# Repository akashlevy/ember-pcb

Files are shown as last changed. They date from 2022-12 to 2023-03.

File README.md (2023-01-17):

# EMBER PCB

This is the PCB for interfacing the EMBER macro with FPGA, power supplies, probing, and power measurement.

## EMBER Sister Repositories

- Digital: https://github.com/akashlevy/ember-digital
- Analog: https://code.stanford.edu/tsmc40r/emblem-analog (PRIVATE & TECHNOLOGY-SPECIFIC)
- Physical Design: https://code.stanford.edu/tsmc40r/emblem-pd (PRIVATE & TECHNOLOGY-SPECIFIC)
- PCB: https://github.com/akashlevy/ember-pcb
- FPGA (Genesys2) Project: https://github.com/akashlevy/ember-fpga
- PetaLinux Configuration: https://github.com/akashlevy/ember-petalinux-config
- Python SPI Environment: https://github.com/akashlevy/ember-python

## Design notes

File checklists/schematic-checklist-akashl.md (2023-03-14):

# Schematic review checklist

## General

* [ ] CAD ERC 100% clean. If some errors are invalid due to toolchain quirks, each exception must be inspected and signed
off as invalid.
* [ ] Verify pin numbers of all schematic symbols against datasheet or external interface specification document (if not yet board proven).
  * [ ] Confirm FMC pins are done correctly
  * [ ] Confirm EMBER pins are oriented correctly
  * [ ] Confirm EMBER pins are mapped correctly to package
  * [ ] Confirm EMBER pins are mapped correctly to socket
  * [ ] Confirm all 256 EMBER pins are routed
* [ ] Schematic symbol matches chosen component package and footprint
* [ ] Thermal pads are connected to correct power rail (may not always be ground)
  * [ ] LP5912 has thermal pads to ground. Hole size on footprint is increased to 10 mil to accommodate design rules.
* [ ] Debug interfaces are not power gated in sleep mode

## Passive components
* [ ] Power/voltage/tolerance ratings specified as required
  * [ ] Regulators work up to 500 mA (200 mA needed)
  * [ ] Switches are rated for up to 300 mA @ 6V (200 mA @ 3.3V needed)
  * [ ] Capacitors are rated for 630 V (3.3V needed)
  * [ ] Ferrite beads are rated for 5A (200 mA needed)
* [ ] Ceramic capacitors appropriately de-rated for C/V curve
  * [ ] Capacitors only used with DC power supplies
* [ ] Polarized components specified in schematic if using electrolytic caps etc.

## Power supply

### System power input

* [ ] Fusing and/or reverse voltage protection at system power inlet
  * [ ] FPGA should take care of this
* [ ] Check total input capacitance and add inrush limiter if needed
  * [ ] Probably ok for test board...
* [ ] Check SMA/coaxial connections (ground shielding on outside, signal on inside)

### Regulators

* [ ] Under/overvoltage protection configured correctly if used
  * [ ] Implemented in regulators and at FPGA and EMBER macro
* [ ] Verify estimated power usage per rail against regulator rating
  * [ ] Max total current is 200 mA (during RESET), which is within all regulators' ratings (500 mA) and FPGA power rating (3 A)
* [ ] Current-sense resistors on power rails after regulator output caps, not in switching loop
  * [ ] Yes, done on power measurement daughter board...
* [ ] Remote sense used on low voltage or high current rails (N/A)
* [ ] Linear regulators and voltage reference ICs are stable with selected output cap ESR
  * [ ] NEED TO DOUBLE CHECK THAT THIS IS OK... OUTPUT CAP CAN BE HIGH IF ALL CAPS ARE POPULATED
* [ ] Confirm power rail sequencing against device datasheets

### Decoupling
* [ ] Decoupling present for all ICs
* [ ] Decoupling meets/exceeds vendor recommendations if specified
* [ ] Bulk decoupling present at PSU

### General
* [ ] All power inputs fed by correct voltage
* [ ] Check high-power discrete semiconductors and passives to confirm they can handle expected load
* [ ] Analog rails filtered/isolated from digital circuitry as needed
  * [ ] Separate planes should help

## Signals

### Digital

* [ ] Signals are correct logic level for input pin
  * [ ] All signals will be at FPGA setting
* [ ] Pullups on all open-drain outputs (N/A)
* [ ] Pulldowns on all PECL outputs (N/A)
* [ ] Termination on all high-speed signals (N/A)
* [ ] AC coupling caps on gigabit transceivers (N/A)
* [ ] TX/RX paired correctly for UART, SPI, MGT, etc (N/A)
* [ ] Differential pair polarity / pairing correct (N/A)
* [ ] Active high/low enable signal polarity correct (N/A)
* [ ] I/O banking rules met on FPGAs etc
* [ ] When using auto-sensing level shifters, ensure the intended receiver doesn't have a pullup/down (N/A)

### Analog

* [ ] RC time constant for attenuators sane given ADC sampling frequency (N/A)
* [ ] Verify frequency response of RF components across entire operating range. Don't assume a "1-100 MHz" amplifier has the (N/A)
same gain across the whole range.
* [ ] Verify polarity of op-amp feedback (N/A)

### Clocks

* [ ] All oscillators meet required jitter / frequency tolerance. Be extra cautious with MEMS oscillators as these tend to have higher jitter. (N/A)
* [ ] Correct load caps provided for discrete crystals (N/A)
* [ ] Crystals only used if IC has an integrated crystal driver (N/A)
* [ ] Banking / clock capable input rules met for clocks going to FPGAs
    * [ ] Xilinx FPGAs: single ended clocks use _P half of differential pairs
    * [ ] If possible, create dummy design with all clocks and other key signals and verify it P&R's properly

### Strap/init pins
* [ ] Pullup/pulldowns on all signals that need defined state at boot
  * [ ] FPGA takes care of this
* [ ] Strap pins connected to correct rail for desired state
  * [ ] DIP switches are strapped to io_pwr
* [ ] JTAG/ICSP connector provided for all programmable devices (N/A)
* [ ] Config/boot flash provided for all FPGAs or MPUs without internal flash (N/A)
* [ ] Reference resistors correct value and reference rail (N/A)

### External interface protection

* [ ] Power outputs (USB etc) current limited
  * [ ] Regulators do this
* [ ] ESD protection on data lines going off board
  * [ ] Exist in EMBER and FPGA

### Debugging / reworkability

* [ ] Use 0-ohm resistors vs direct hard-wiring for strap pins when possible (N/A)
* [ ] Provide multiple ground clips/points for scope probes
  * [ ] Available on power header and analog header
* [ ] Dedicated ground in close proximity to analog test points
* [ ] Test points on all power rails
  * [ ] Accessible through power headers
* [ ] Test points on interesting signals which may need probing for bringup/debug
  * [ ] Heartbeat
  * [ ] All EMBER signals can be probed on bottom through socket

## Thermal

* [ ] Power estimates for all large / high power ICs
  * [ ] EMBER should never exceed 100 mA
* [ ] Thermal calculations for all large / high power ICs
* [ ] Specify heatsinks as needed
  * [ ] Thermal vias on regulator ICs connect to ground plane

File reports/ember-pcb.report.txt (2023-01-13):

PCB statistics report
=====================
- Date: Friday, January 13, 2023 at 03:17:59 PM
- Project: ember-pcb
- Board name: ember-pcb

Board
-----
- Width: 4695.00 mils
- Height: 3935.00 mils
- Area: 18474825.00 sq. mils

Pads
----
- Through hole: 506
- SMD: 482
- Connector: 0
- NPTH: 8

Vias
----
- Through vias: 378
- Blind/buried: 0
- Micro vias: 0

Components
----------

| | Front Side | Back Side | Total |
|---|---|---|---|
|THT: | 8  | 0  | 8  |
|SMD: | 23  | 1  | 24  |
|Total:  | 31  | 1  | 32  |
| | | | |

Drill holes
-----------

| Count | Shape | X Size | Y Size | Plated | Via/Pad | Start Layer | Stop Layer |
|---|---|---|---|---|---|---|---|
| 441 | Round | 33.86 mils | 33.86 mils | PTH | Pad | F.Cu | B.Cu |
| 349 | Round | 10.00 mils | 10.00 mils | PTH | Via | F.Cu | B.Cu |
| 43 | Round | 39.37 mils | 39.37 mils | PTH | Pad | F.Cu | B.Cu |
| 29 | Round | 15.75 mils | 15.75 mils | PTH | Via | F.Cu | B.Cu |
| 10 | Round | 59.06 mils | 59.06 mils | PTH | Pad | F.Cu | B.Cu |
| 6 | Round | 10.00 mils | 10.00 mils | PTH | Pad | F.Cu | B.Cu |
| 4 | Round | 35.43 mils | 35.43 mils | NPTH | Pad | F.Cu | B.Cu |
| 4 | Round | 31.50 mils | 31.50 mils | PTH | Pad | F.Cu | B.Cu |
| 2 | Round | 98.43 mils | 98.43 mils | NPTH | Pad | F.Cu | B.Cu |
| 2 | Round | 98.43 mils | 98.43 mils | PTH | Pad | F.Cu | B.Cu |
| 2 | Round | 50.00 mils | 50.00 mils | NPTH | Pad | F.Cu | B.Cu |

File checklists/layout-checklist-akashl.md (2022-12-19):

# Layout review checklist

## General

* [ ] [Schematic review](schematic-checklist.md) complete and signed off, including pin swaps done during layout
* [ ] Layout DRC 100% clean

## Decoupling

* [ ] Decoupling caps as close to power pins as possible
  * [ ] Huge planes, can solder on decoupling caps onto power pins on socket after the fact as well
* [ ] Low inductance mounting used for decoupling (prefer ViP if available, otherwise "[]8" shaped side vias (N/A)

## DFM / yield enhancement

* [ ] All design rules within manufacturer's capability (N/A)
* [ ] Minimize use of vias/traces that push fab limits
* [ ] Controlled impedance specified in fab notes if applicable (N/A)
* [ ] Confirm impedance calculations include soldermask, or mask removed from RF traces (N/A)
* [ ] Stackup verified with manufacturer and specified in fab notes
* [ ] Board finish specified in fab notes
* [ ] If panelizing, add panel location indicators for identifying location-specific reflow issues (N/A)
* [ ] (recommended) Layer number markers specified to ensure correct assembly
* [ ] Fiducials present (on both sides of board) if targeting automated assembly
* [ ] Fiducial pattern asymmetric to detect rotated or flipped boards
* [ ] Soldermask/copper clearance on fiducials respected
* [ ] Panelization specified if required (N/A)

## Footprints

* [ ] Confirm components are available in the selected package
* [ ] Confirm components (especially connectors and power regulators) are capable of desired current in the selected package
* [ ] Verify schematic symbol matches the selected package
* [ ] Confirm pinout diagram is from top vs bottom of package
* [ ] (recommended) PCB printed 1:1 on paper and checked against physical parts
* [ ] 3D models obtained (if available) and checked against footprints
* [ ] Soldermask apertures on all SMT lands and PTH pads

## Differential pairs
* [ ] Routed differentially
* [ ] Skew matched
* [ ] Correct clearance to non-coupled nets

## High-speed signals

* [ ] Sufficient clearance to potential aggressors
* [ ] Length matched if required
  * [ ] See reports/ember-pcb.nets.xlsx for statistics on signal net length from FPGA
* [ ] Minimize crossing reference plane splits/slots or changing layers, use caps/stitching vias if unavoidable
* [ ] Confirm fab can do copper to edge of PCB for edge launch connectors
* [ ] Double-check pad width on connectors and add plane cutouts if needed to minimize impedance discontinuities (N/A)

## Power
* [ ] Minimal slots in planes from via antipads
* [ ] Sufficient width for planes/traces for required current

## Sensitive analog
* [ ] Guard ring / EMI cages provided if needed (N/A)
* [ ] Physically separated from high current SMPS or other noise sources (N/A)
* [ ] Consider microphone effect on MLCCs if near strong sound sources (N/A)

## Mechanical
* [ ] Confirm all connectors to other systems comply with the appropriate mechanical standard (connector orientation, key position, etc)
  * [ ] Confirm FMC orientation is correct (see Xilinx FMC female adapter photo in docs vs. 3D view of board)
  * [ ] Confirm PGA orientation is correct
* [ ] LEDs, buttons, and other UI elements on outward-facing side of board
* [ ] Keep-outs around PCB perimeter, card guides, panelization mouse-bites, etc respected
* [ ] Stress-sensitive components (MLCC) sufficiently clear from V-score or mouse bite locations, and oriented to reduce (N/A)
bending stress
* [ ] Clearance around large ICs for heatsinks/fans if required (N/A)
* [ ] Clearance around pluggable connectors for mating cable/connector
* [ ] Clearance around mounting holes for screws
* [ ] Plane keepouts and clearance provided for shielded connectors, magnetics, etc (N/A)
* [ ] Confirm PCB dimensions and mounting hole size/placement against enclosure or card rack design
* [ ] Verify mounting hole connection/isolation
  * [ ] Grounded
* [ ] Components not physically overlapping/colliding
* [ ] Clearance provided around solder-in test points for probe tips

## Thermal

* [ ] Thermal reliefs used for plane connections (unless via is used for heatsinking)
* [ ] Solid connections used to planes if heatsinking
  * [ ] Used for regulators
* [ ] Ensure thermal balance on SMT chip components to minimize risk of tombstoning

## Solder paste

* [z] No uncapped vias in pads (except low-power QFNs where some voiding is acceptable)
* [ ] QFN paste prints segmented (N/A)
* [ ] Small pads 100% size, larger pads reduced to avoid excessive solder volume
* [ ] No paste apertures on card edge connectors or test points

## Solder mask

* [ ] Confirm SMD vs NSMD pad geometry
* [ ] Adequate clearance around pads (typ. 50 um)

## Silkscreen

* [ ] Text size within fab limits
* [ ] Text not overlapping drills or component pads
* [ ] Text removed entirely in, or moved outside of, high component/via density areas
* [ ] Traceability markings (rev, date, name, etc) provided
* [ ] Silkscreen box provided for writing/sticking serial number (N/A)
* [ ] Text mirrored properly on bottom layer
* [ ] Test points labeled if space permits

## Flex specific
* [ ] Components oriented to reduce bending forces (N/A)
* [ ] Teardrops on all wire-to-pad connections (N/A)

## CAM production
* [ ] KiCAD specific: rerun DRC and zone fills before exporting CAM files to ensure proper results
* [ ] Export gerber/drill files at the same time to ensure consistency
* [ ] Visually verify final CAM files to ensure no obvious misalignments

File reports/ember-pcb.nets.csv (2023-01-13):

Net Code | Net Name | Pad Count | Via Count | Via Length | Track Length | Die Length | Net Length
070 | /rram_busy | 2 | 0 | 0.00 mils | 3937.01 mils | 0.00 mils | 3937.01 mils
089 | /sclk | 2 | 0 | 0.00 mils | 3937.02 mils | 0.00 mils | 3937.02 mils
090 | /sc | 2 | 0 | 0.00 mils | 3937.28 mils | 0.00 mils | 3937.28 mils
091 | /mosi | 2 | 2 | 104.49 mils | 3832.61 mils | 0.00 mils | 3937.10 mils
092 | /read_dac_config_1 | 2 | 1 | 9.12 mils | 3919.43 mils | 0.00 mils | 3928.55 mils
093 | /rst_n | 2 | 0 | 0.00 mils | 3937.02 mils | 0.00 mils | 3937.02 mils
094 | /read_dac_config_0 | 2 | 1 | 52.25 mils | 3833.52 mils | 0.00 mils | 3885.76 mils
095 | /byp | 3 | 1 | 61.37 mils | 3539.87 mils | 0.00 mils | 3601.24 mils
096 | /man | 3 | 1 | 61.37 mils | 3217.64 mils | 0.00 mils | 3279.01 mils
097 | /di_42 | 2 | 1 | 52.25 mils | 3833.21 mils | 0.00 mils | 3885.46 mils
098 | /clamp_ref_1 | 2 | 1 | 52.25 mils | 3832.71 mils | 0.00 mils | 3884.96 mils
099 | /clamp_ref_2 | 2 | 1 | 52.25 mils | 3832.61 mils | 0.00 mils | 3884.86 mils
100 | /clamp_ref_3 | 2 | 1 | 9.12 mils | 3927.91 mils | 0.00 mils | 3937.03 mils
101 | /clamp_ref_4 | 2 | 1 | 9.12 mils | 3918.77 mils | 0.00 mils | 3927.90 mils
102 | /wl_dac_config_0 | 2 | 1 | 52.25 mils | 3832.92 mils | 0.00 mils | 3885.17 mils
103 | /core_pwr | 9 | 4 | 245.48 mils | 2419.02 mils | 0.00 mils | 2664.50 mils
104 | /vdd_fsm | 9 | 0 | 0.00 mils | 0.00 mils | 0.00 mils | 0.00 mils
105 | /vdd | 11 | 0 | 0.00 mils | 0.00 mils | 0.00 mils | 0.00 mils
106 | /vdd_dac | 7 | 0 | 0.00 mils | 0.00 mils | 0.00 mils | 0.00 mils
107 | /vsa | 6 | 0 | 0.00 mils | 0.00 mils | 0.00 mils | 0.00 mils
110 | /io_pwr | 8 | 4 | 245.48 mils | 2755.67 mils | 0.00 mils | 3001.15 mils
111 | /vddio_fsm | 17 | 0 | 0.00 mils | 0.00 mils | 0.00 mils | 0.00 mils
112 | /vddio | 13 | 0 | 0.00 mils | 0.00 mils | 0.00 mils | 0.00 mils
113 | /vddio_dac | 13 | 0 | 0.00 mils | 0.00 mils | 0.00 mils | 0.00 mils
116 | /wl_source_pin | 2 | 0 | 0.00 mils | 2380.95 mils | 0.00 mils | 2380.95 mils
117 | /bl_source_pin | 3 | 0 | 0.00 mils | 5710.48 mils | 0.00 mils | 5710.48 mils
118 | /sl_source_pin | 3 | 0 | 0.00 mils | 4810.73 mils | 0.00 mils | 4810.73 mils
119 | /iref_test | 2 | 0 | 0.00 mils | 5828.94 mils | 0.00 mils | 5828.94 mils
120 | /vdd_test | 2 | 0 | 0.00 mils | 5487.40 mils | 0.00 mils | 5487.40 mils
282 | /di_47 | 2 | 1 | 52.25 mils | 3884.76 mils | 0.00 mils | 3937.01 mils
283 | /di_21 | 2 | 1 | 9.12 mils | 3919.18 mils | 0.00 mils | 3928.31 mils
284 | /rram_addr_0 | 2 | 1 | 9.12 mils | 3927.94 mils | 0.00 mils | 3937.06 mils
285 | /di_8 | 2 | 1 | 52.25 mils | 3832.53 mils | 0.00 mils | 3884.78 mils
286 | /di_36 | 2 | 1 | 52.25 mils | 3887.04 mils | 0.00 mils | 3939.29 mils
287 | /rram_addr_2 | 2 | 1 | 52.25 mils | 3884.77 mils | 0.00 mils | 3937.02 mils
288 | /sa_en | 2 | 1 | 9.12 mils | 3928.00 mils | 0.00 mils | 3937.12 mils
289 | /di_44 | 2 | 1 | 9.12 mils | 3929.52 mils | 0.00 mils | 3938.64 mils
290 | /di_43 | 2 | 1 | 52.25 mils | 3885.10 mils | 0.00 mils | 3937.35 mils
291 | /di_22 | 2 | 1 | 52.25 mils | 3884.75 mils | 0.00 mils | 3937.00 mils
292 | /rram_addr_6 | 2 | 1 | 9.12 mils | 3918.77 mils | 0.00 mils | 3927.90 mils
293 | /di_14 | 2 | 1 | 52.25 mils | 3884.91 mils | 0.00 mils | 3937.16 mils
294 | /di_4 | 2 | 1 | 52.25 mils | 3884.74 mils | 0.00 mils | 3936.99 mils
295 | /di_37 | 2 | 1 | 9.12 mils | 3920.35 mils | 0.00 mils | 3929.47 mils
296 | /di_39 | 2 | 1 | 9.12 mils | 3889.48 mils | 0.00 mils | 3898.60 mils
297 | /sa_do_13 | 2 | 1 | 9.12 mils | 3927.87 mils | 0.00 mils | 3936.99 mils
298 | /sa_do_36 | 2 | 1 | 52.25 mils | 3891.81 mils | 0.00 mils | 3944.05 mils
299 | /miso | 2 | 0 | 0.00 mils | 3937.11 mils | 0.00 mils | 3937.11 mils
300 | /sa_do_41 | 2 | 1 | 9.12 mils | 3927.86 mils | 0.00 mils | 3936.98 mils
301 | /set_rst | 2 | 1 | 52.25 mils | 3832.54 mils | 0.00 mils | 3884.79 mils
302 | /read_ref_5 | 2 | 1 | 9.12 mils | 3918.72 mils | 0.00 mils | 3927.84 mils
303 | /rram_addr_4 | 2 | 1 | 52.25 mils | 3887.68 mils | 0.00 mils | 3939.93 mils
304 | /rram_addr_5 | 2 | 1 | 9.12 mils | 3927.88 mils | 0.00 mils | 3937.01 mils
305 | /read_ref_4 | 2 | 1 | 9.12 mils | 3927.03 mils | 0.00 mils | 3936.15 mils
306 | /rram_addr_11 | 2 | 1 | 9.12 mils | 3919.22 mils | 0.00 mils | 3928.35 mils
307 | /read_ref_1 | 2 | 1 | 52.25 mils | 3884.71 mils | 0.00 mils | 3936.95 mils
308 | /rram_addr_15 | 2 | 1 | 9.12 mils | 3920.29 mils | 0.00 mils | 3929.41 mils
309 | /di_27 | 2 | 1 | 52.25 mils | 3833.78 mils | 0.00 mils | 3886.03 mils
310 | /di_32 | 2 | 1 | 9.12 mils | 3918.87 mils | 0.00 mils | 3927.99 mils
311 | /di_33 | 2 | 1 | 52.25 mils | 3884.05 mils | 0.00 mils | 3936.30 mils
312 | /di_35 | 2 | 2 | 61.37 mils | 3810.98 mils | 0.00 mils | 3872.35 mils
313 | /di_38 | 2 | 2 | 18.25 mils | 3916.73 mils | 0.00 mils | 3934.98 mils
314 | /di_40 | 2 | 2 | 61.37 mils | 3813.09 mils | 0.00 mils | 3874.46 mils
315 | /rram_addr_3 | 2 | 1 | 52.25 mils | 3885.79 mils | 0.00 mils | 3938.03 mils
316 | /di_46 | 2 | 2 | 61.37 mils | 3814.44 mils | 0.00 mils | 3875.81 mils
317 | /read_ref_0 | 2 | 1 | 52.25 mils | 3834.56 mils | 0.00 mils | 3886.81 mils
318 | /read_ref_3 | 2 | 2 | 61.37 mils | 3874.85 mils | 0.00 mils | 3936.22 mils
319 | /di_23 | 2 | 2 | 61.37 mils | 3875.65 mils | 0.00 mils | 3937.02 mils
320 | /rram_addr_7 | 2 | 1 | 9.12 mils | 3918.77 mils | 0.00 mils | 3927.89 mils
321 | /rram_addr_9 | 2 | 1 | 9.12 mils | 3916.36 mils | 0.00 mils | 3925.48 mils
322 | /di_26 | 2 | 1 | 52.25 mils | 3887.59 mils | 0.00 mils | 3939.83 mils
323 | /di_0 | 2 | 1 | 52.25 mils | 3884.76 mils | 0.00 mils | 3937.00 mils
324 | /we | 2 | 1 | 52.25 mils | 3832.83 mils | 0.00 mils | 3885.08 mils
325 | /read_dac_config_2 | 2 | 1 | 9.12 mils | 3918.76 mils | 0.00 mils | 3927.89 mils
326 | /bsl_dac_config_2 | 2 | 3 | 113.62 mils | 3823.42 mils | 0.00 mils | 3937.04 mils
327 | /sa_do_32 | 2 | 1 | 9.12 mils | 3928.14 mils | 0.00 mils | 3937.27 mils
328 | /sa_do_19 | 2 | 1 | 9.12 mils | 3927.88 mils | 0.00 mils | 3937.01 mils
329 | /sa_do_43 | 2 | 1 | 52.25 mils | 3886.08 mils | 0.00 mils | 3938.33 mils
330 | /sa_do_30 | 2 | 1 | 52.25 mils | 3885.75 mils | 0.00 mils | 3938.00 mils
331 | /wl_dac_config_3 | 2 | 1 | 9.12 mils | 3927.90 mils | 0.00 mils | 3937.03 mils
332 | /wl_dac_config_5 | 2 | 1 | 52.25 mils | 3833.35 mils | 0.00 mils | 3885.60 mils
333 | /di_25 | 2 | 3 | 165.86 mils | 3708.25 mils | 0.00 mils | 3874.12 mils
334 | /di_28 | 2 | 2 | 18.25 mils | 3918.82 mils | 0.00 mils | 3937.07 mils
335 | /di_29 | 2 | 2 | 61.37 mils | 3875.44 mils | 0.00 mils | 3936.81 mils
336 | /sa_do_42 | 2 | 1 | 52.25 mils | 3885.72 mils | 0.00 mils | 3937.97 mils
337 | /wl_dac_config_2 | 2 | 1 | 9.12 mils | 3918.74 mils | 0.00 mils | 3927.86 mils
338 | /sa_do_44 | 2 | 1 | 52.25 mils | 3884.11 mils | 0.00 mils | 3936.36 mils
339 | /di_18 | 2 | 1 | 9.12 mils | 3918.71 mils | 0.00 mils | 3927.84 mils
340 | /di_24 | 2 | 1 | 9.12 mils | 3918.76 mils | 0.00 mils | 3927.88 mils
341 | /rram_addr_10 | 2 | 1 | 9.12 mils | 3918.79 mils | 0.00 mils | 3927.91 mils
342 | /read_ref_2 | 2 | 1 | 9.12 mils | 3918.80 mils | 0.00 mils | 3927.92 mils
343 | /di_45 | 2 | 1 | 9.12 mils | 3918.87 mils | 0.00 mils | 3927.99 mils
344 | /di_16 | 2 | 1 | 52.25 mils | 3832.05 mils | 0.00 mils | 3884.30 mils
345 | /rram_addr_8 | 2 | 1 | 52.25 mils | 3834.38 mils | 0.00 mils | 3886.62 mils
346 | /read_dac_config_3 | 2 | 1 | 52.25 mils | 3832.03 mils | 0.00 mils | 3884.28 mils
347 | /wl_dac_config_6 | 2 | 1 | 9.12 mils | 3918.76 mils | 0.00 mils | 3927.89 mils
348 | /wl_dac_en | 2 | 1 | 52.25 mils | 3832.04 mils | 0.00 mils | 3884.28 mils
349 | /sa_do_2 | 2 | 1 | 9.12 mils | 3919.53 mils | 0.00 mils | 3928.66 mils
350 | /di_2 | 2 | 1 | 9.12 mils | 3918.89 mils | 0.00 mils | 3928.01 mils
351 | /di_17 | 2 | 1 | 9.12 mils | 3929.10 mils | 0.00 mils | 3938.22 mils
352 | /di_20 | 2 | 1 | 52.25 mils | 3832.62 mils | 0.00 mils | 3884.86 mils
353 | /di_19 | 2 | 1 | 9.12 mils | 3918.76 mils | 0.00 mils | 3927.88 mils
354 | /bleed_en | 2 | 2 | 113.62 mils | 3813.90 mils | 0.00 mils | 3927.52 mils
355 | /wl_en | 2 | 1 | 9.12 mils | 3918.76 mils | 0.00 mils | 3927.88 mils
356 | /sa_do_0 | 2 | 1 | 52.25 mils | 3886.34 mils | 0.00 mils | 3938.59 mils
357 | /sa_do_4 | 2 | 1 | 9.12 mils | 3924.17 mils | 0.00 mils | 3933.29 mils
358 | /di_12 | 2 | 1 | 52.25 mils | 3885.00 mils | 0.00 mils | 3937.25 mils
359 | /di_15 | 2 | 1 | 52.25 mils | 3884.75 mils | 0.00 mils | 3937.00 mils
360 | /di_13 | 2 | 2 | 61.37 mils | 3874.13 mils | 0.00 mils | 3935.50 mils
361 | /sa_do_3 | 2 | 1 | 52.25 mils | 3885.07 mils | 0.00 mils | 3937.31 mils
362 | /sa_do_1 | 2 | 1 | 9.12 mils | 3927.89 mils | 0.00 mils | 3937.01 mils
363 | /clamp_ref_5 | 2 | 1 | 9.12 mils | 3918.72 mils | 0.00 mils | 3927.84 mils
364 | /di_11 | 2 | 2 | 61.37 mils | 3816.03 mils | 0.00 mils | 3877.40 mils
365 | /di_9 | 2 | 1 | 52.25 mils | 3885.49 mils | 0.00 mils | 3937.74 mils
366 | /di_10 | 2 | 1 | 9.12 mils | 3927.67 mils | 0.00 mils | 3936.79 mils
367 | /sa_do_7 | 2 | 1 | 52.25 mils | 3832.81 mils | 0.00 mils | 3885.06 mils
368 | /sa_do_10 | 2 | 1 | 9.12 mils | 3919.97 mils | 0.00 mils | 3929.09 mils
369 | /sa_do_6 | 2 | 1 | 52.25 mils | 3832.50 mils | 0.00 mils | 3884.75 mils
370 | /di_7 | 2 | 1 | 9.12 mils | 3917.75 mils | 0.00 mils | 3926.87 mils
371 | /di_5 | 2 | 2 | 61.37 mils | 3814.47 mils | 0.00 mils | 3875.84 mils
372 | /di_6 | 2 | 1 | 52.25 mils | 3832.63 mils | 0.00 mils | 3884.88 mils
373 | /sa_do_11 | 2 | 1 | 52.25 mils | 3884.81 mils | 0.00 mils | 3937.05 mils
374 | /sa_do_12 | 2 | 1 | 9.12 mils | 3918.76 mils | 0.00 mils | 3927.88 mils
375 | /sa_do_9 | 2 | 1 | 52.25 mils | 3832.82 mils | 0.00 mils | 3885.07 mils
376 | /sa_do_38 | 2 | 1 | 9.12 mils | 3918.77 mils | 0.00 mils | 3927.90 mils
377 | /sa_rdy | 2 | 1 | 9.12 mils | 3918.74 mils | 0.00 mils | 3927.86 mils
378 | /sa_do_31 | 2 | 1 | 9.12 mils | 3918.76 mils | 0.00 mils | 3927.88 mils
379 | /rram_addr_1 | 2 | 1 | 52.25 mils | 3833.13 mils | 0.00 mils | 3885.38 mils
380 | /di_30 | 2 | 2 | 61.37 mils | 3815.27 mils | 0.00 mils | 3876.64 mils
381 | /wl_dac_config_1 | 2 | 1 | 52.25 mils | 3831.79 mils | 0.00 mils | 3884.04 mils
382 | /sa_do_18 | 2 | 1 | 52.25 mils | 3832.54 mils | 0.00 mils | 3884.78 mils
383 | /sa_do_16 | 2 | 2 | 113.62 mils | 3812.76 mils | 0.00 mils | 3926.38 mils
384 | /sa_do_8 | 2 | 1 | 9.12 mils | 3918.82 mils | 0.00 mils | 3927.94 mils
385 | /di_3 | 2 | 1 | 9.12 mils | 3920.82 mils | 0.00 mils | 3929.94 mils
386 | /sa_do_21 | 2 | 1 | 52.25 mils | 3832.67 mils | 0.00 mils | 3884.92 mils
387 | /sa_do_20 | 2 | 1 | 9.12 mils | 3921.96 mils | 0.00 mils | 3931.09 mils
388 | /sa_do_17 | 2 | 1 | 52.25 mils | 3832.53 mils | 0.00 mils | 3884.77 mils
389 | /di_1 | 2 | 1 | 9.12 mils | 3918.82 mils | 0.00 mils | 3927.94 mils
390 | /bl_en | 2 | 1 | 52.25 mils | 3886.12 mils | 0.00 mils | 3938.37 mils
391 | /sa_do_23 | 2 | 2 | 61.37 mils | 3875.99 mils | 0.00 mils | 3937.36 mils
392 | /sa_do_22 | 2 | 1 | 52.25 mils | 3884.76 mils | 0.00 mils | 3937.01 mils
393 | /sa_do_15 | 2 | 1 | 9.12 mils | 3919.40 mils | 0.00 mils | 3928.52 mils
394 | /bsl_dac_en | 2 | 2 | 61.37 mils | 3814.24 mils | 0.00 mils | 3875.61 mils
395 | /bsl_dac_config_4 | 2 | 2 | 61.37 mils | 3815.96 mils | 0.00 mils | 3877.33 mils
396 | /sa_do_27 | 2 | 1 | 9.12 mils | 3918.78 mils | 0.00 mils | 3927.90 mils
397 | /bsl_dac_config_0 | 2 | 1 | 52.25 mils | 3832.64 mils | 0.00 mils | 3884.89 mils
398 | /sa_do_45 | 2 | 1 | 52.25 mils | 3832.03 mils | 0.00 mils | 3884.28 mils
399 | /sa_do_39 | 2 | 1 | 9.12 mils | 3919.64 mils | 0.00 mils | 3928.77 mils
400 | /read_dac_en | 2 | 1 | 52.25 mils | 3832.22 mils | 0.00 mils | 3884.46 mils
401 | /sa_do_37 | 2 | 1 | 52.25 mils | 3833.89 mils | 0.00 mils | 3886.13 mils
402 | /sa_do_29 | 2 | 1 | 52.25 mils | 3833.07 mils | 0.00 mils | 3885.31 mils
403 | /sa_do_28 | 2 | 1 | 9.12 mils | 3916.34 mils | 0.00 mils | 3925.46 mils
404 | /sa_do_26 | 2 | 1 | 52.25 mils | 3832.02 mils | 0.00 mils | 3884.27 mils
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

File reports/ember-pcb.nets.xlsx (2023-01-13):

Net Code | Net Name | Pad Count | Via Count | Via Length | Track Length | Die Length | Net Length
70 | /rram_busy | 2 | 0 | 0 | 3937.01 | 0 | 3937.01
89 | /sclk | 2 | 0 | 0 | 3937.02 | 0 | 3937.02
90 | /sc | 2 | 0 | 0 | 3937.28 | 0 | 3937.28
91 | /mosi | 2 | 2 | 104.49 | 3832.61 | 0 | 3937.1
92 | /read_dac_config_1 | 2 | 1 | 9.12 | 3919.43 | 0 | 3928.55
93 | /rst_n | 2 | 0 | 0 | 3937.02 | 0 | 3937.02
94 | /read_dac_config_0 | 2 | 1 | 52.25 | 3833.52 | 0 | 3885.76
95 | /byp | 3 | 1 | 61.37 | 3539.87 | 0 | 3601.24
96 | /man | 3 | 1 | 61.37 | 3217.64 | 0 | 3279.01
97 | /di_42 | 2 | 1 | 52.25 | 3833.21 | 0 | 3885.46
98 | /clamp_ref_1 | 2 | 1 | 52.25 | 3832.71 | 0 | 3884.96
99 | /clamp_ref_2 | 2 | 1 | 52.25 | 3832.61 | 0 | 3884.86
100 | /clamp_ref_3 | 2 | 1 | 9.12 | 3927.91 | 0 | 3937.03
101 | /clamp_ref_4 | 2 | 1 | 9.12 | 3918.77 | 0 | 3927.9
102 | /wl_dac_config_0 | 2 | 1 | 52.25 | 3832.92 | 0 | 3885.17
103 | /core_pwr | 9 | 4 | 245.48 | 2419.02 | 0 | 2664.5
104 | /vdd_fsm | 9 | 0 | 0 | 0 | 0 | 0
105 | /vdd | 11 | 0 | 0 | 0 | 0 | 0
106 | /vdd_dac | 7 | 0 | 0 | 0 | 0 | 0
107 | /vsa | 6 | 0 | 0 | 0 | 0 | 0
110 | /io_pwr | 8 | 4 | 245.48 | 2755.67 | 0 | 3001.15
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

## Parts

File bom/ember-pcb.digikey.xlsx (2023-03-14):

Country of Origin may be different at time of shipment.
The HTSUS and ECCN information shown is for informational purposes only and is not a representation or warranty as to the accuracy or reliability of these classifications. All information is provided "as is" and is subject to change without notice. Any use made of the information provided is without recourse to Digi-Key and at the user's risk.
Index | Manufacturer Part Number | Manufacturer Name | Description | Availability | Stock Status | Attrition % | Requested Quantity 1 | Pack Quantity 1 | Pack Type 1 | Digi-Key Part Number 1 | Unit Price 1 | Extended Price 1 | Minimum Order Quantity 1 | Customer Reference | Requested Part Number | Lead Weeks | Datasheet | Reference Designator | US Import Tariff | Note | Part Status | RoHS Status | ECCN | HTSUS | Country of Origin | Environmental Information | Original Part numbers | Image
1 | T495B226K010ATE500 | KEMET | CAP TANT 22UF 10% 10V 1411 | 3,379 | In Stock |  | 4 | 4 | Cut Tape (CT) | 399-18339-1-ND | 1.63000 | $6.52 | 1 |  | 399-18339-1-ND | 19 | https://api.kemet.com/component-edge/download/datasheet/T495B226K010ATE500.pdf | C1, C3, C6, C8 | N/A |  | Active | ROHS3 Compliant | EAR99 | 8532.21.0050 | Mexico |  | 399-18339-1-ND | https://media.digikey.com/Photos/Kemet%20Photos/MFG_T495-Series.jpg
2 | C3225X7T2J104K160AE | TDK Corporation | CAP CER 0.1UF 630V X7T 1210 | 50,474 | In Stock |  | 5 | 5 | Cut Tape (CT) | 445-8907-1-ND | 0.65000 | $3.25 | 1 |  | 445-8907-1-ND | 28 | https://product.tdk.com/system/files/dam/doc/product/capacitor/ceramic/mlcc/catalog/mlcc_commercial_soft_en.pdf | C2, C5, C7, C10, C14 | N/A |  | Active | ROHS3 Compliant | EAR99 | 8532.24.0020 | Japan | https://product.tdk.com/system/files/dam/doc/product/capacitor/ceramic/mlcc/rohs/mlccrohs_commercial_soft_en.pdf|https://product.tdk.com/en/environment/index.html | 445-8907-1-ND | https://media.digikey.com/Renders/TDK%20Renders/1210-(3225-Metric)-2,80mm-C-Series.jpg
3 | T494B106K025AT | KEMET | CAP TANT 10UF 10% 25V 1411 | 13,167 | In Stock |  | 2 | 2 | Cut Tape (CT) | 399-5126-1-ND | 1.53000 | $3.06 | 1 |  | 399-5126-1-ND | 21 | https://api.kemet.com/component-edge/download/datasheet/T494B106K025AT.pdf | C4, C9 | N/A |  | Active | ROHS3 Compliant | EAR99 | 8532.21.0050 | Mexico |  | 399-5126-1-ND | https://media.digikey.com/photos/Kemet%20Photos/T494B685K016AT.JPG
4 | C0603C270J5GAC7411 | KEMET | CAP CER 27PF 50V C0G/NP0 0603 | 85,149 | In Stock |  | 2 | 2 | Cut Tape (CT) | 399-C0603C270J5GAC7411CT-ND | 0.10000 | $0.20 | 1 |  | 399-C0603C270J5GAC7411CT-ND | 37 | https://connect.kemet.com:7667/gateway/IntelliData-ComponentDocumentation/1.0/download/datasheet/C0603C270J5GAC7411 | C11, C12 | N/A |  | Active | ROHS3 Compliant | EAR99 | 8532.24.0020 | Mexico |  | 399-C0603C270J5GAC7411CT-ND | https://media.digikey.com/Renders/Kemet%20Renders/0603-(1608-Metric)-1,60x0,80x0,87mm.jpg
5 | TAJB475K035RNJ | KYOCERA AVX | CAP TANT 4.7UF 10% 35V 1411 | 71,695 | In Stock |  | 1 | 1 | Cut Tape (CT) | 478-1691-1-ND | 0.53000 | $0.53 | 1 |  | 478-1691-1-ND | 13 | https://datasheets.kyocera-avx.com/TAJ.pdf | C13 | N/A |  | Active | ROHS3 Compliant | EAR99 | 8532.21.0050 | El Salvador |  | 478-1691-1-ND | https://media.digikey.com/photos/AVX%20Photos/OxiCap%20NOJ%20SERIES%201.9H,3.5L,2.8W.jpg
6 | LT Q39E-Q1OO-25-1 | OSRAM Opto (ams OSRAM) | LED GREEN DIFFUSED 0603 SMD | 2,295 | In Stock |  | 2 | 2 | Cut Tape (CT) | 475-3441-1-ND | 0.43000 | $0.86 | 1 |  | 475-3441-1-ND | 14 | https://dammedia.osram.info/media/resource/hires/osram-dam-2493475/LT%20Q39E.pdf | D1, D2 | N/A |  | Active | ROHS3 Compliant | EAR99 | 8541.41.0000 | Taiwan |  | 475-3441-1-ND | https://media.digikey.com/Renders/Osram%20Opto%20Renders/LB-Q39E.jpg
7 | 28C0236-0JW-10 | Laird-Signal Integrity Products | FERRITE BEAD 998 OHM RADIAL 1LN | 119,407 | In Stock |  | 2 | 2 | Bulk | 240-2493-ND | 0.90000 | $1.80 | 1 |  | 240-2493-ND | 22 | https://media.digikey.com/pdf/Data%20Sheets/Laird%20Technologies/EMI_Filtering_and_RF_Inductors.pdf | FB1, FB2 | N/A |  | Active | ROHS3 Compliant | EAR99 | 8548.00.0000 | China |  | 240-2493-ND | https://media.digikey.com/photos/Steward%20Photos/28C0236-0JW-10.jpg
8 | ASP-134602-01 | Samtec Inc. | CONN ARRAY PLUG 400POS SMD GOLD | 1,956 | In Stock |  | 1 | 1 | Cut Tape (CT) | 612-ASP-134602-01CT-ND | 29.88000 | $29.88 | 1 |  | 612-ASP-134602-01CT-ND | 11 | http://suddendocs.samtec.com/prints/asp-134602-01.pdf | J1 | N/A |  | Active | ROHS3 Compliant | EAR99 | 8536.69.4040 | Costa Rica |  | 612-ASP-134602-01CT-ND | https://media.digikey.com/Photos/Samtec%20Photos/ASP-134602-01_TOP.JPG
9 | PH2-12-UA | Adam Tech | CONN HEADER VERT 12POS 2.54MM | 16,413 | In Stock |  | 1 | 1 | Bag | 2057-PH2-12-UA-ND | 0.20000 | $0.20 | 1 |  | 2057-PH2-12-UA-ND | 10 | https://app.adam-tech.com/products/download/data_sheet/202065/ph2-xx-ua-data-sheet.pdf | J2 | N/A |  | Active | ROHS3 Compliant | EAR99 | 8536.69.4040 | Taiwan |  | 2057-PH2-12-UA-ND | https://media.digikey.com/Renders/Adam-Tech%20Renders/PH2-xx-UA.jpg
10 | 0732512200 | Molex | CONN SMA JACK R/A 50 OHM PCB | 24,681 | In Stock |  | 4 | 4 | Bulk | WM9352-ND | 6.88000 | $27.52 | 1 |  | WM9352-ND | 8 | https://www.molex.com/pdm_docs/sd/732512200_sd.pdf | J3, J6, J8, J9 | N/A |  | Active | ROHS3 Compliant | EAR99 | 8536.69.4010 | Taiwan | https://www.molex.com/datasheets/rohspdf/0732512200_rohs.pdf | WM9352-ND | https://media.digikey.com/Photos/Molex/0732512200.jpg
11 | 10129381-924001BLF | Amphenol ICC (FCI) | CONN HEADER VERT 24POS 2.54MM | 283 | In Stock |  | 1 | 1 | Bulk | 10129381-924001BLF-ND | 0.44000 | $0.44 | 1 |  | 10129381-924001BLF-ND | 8 | https://cdn.amphenol-cs.com/media/wysiwyg/files/drawing/10129381.pdf | J4 | May apply on shipments to the U.S. |  | Active | RoHS Compliant | EAR99 | 8536.69.4040 | China |  | 10129381-924001BLF-ND | https://media.digikey.com/Photos/Amphenol%20Photos/10129381-924001BLF.jpg
12 | PH1-07-UA | Adam Tech | CONN HEADER VERT 7POS 2.54MM | 21,935 | In Stock |  | 1 | 1 | Bag | 2057-PH1-07-UA-ND | 0.15000 | $0.15 | 1 |  | 2057-PH1-07-UA-ND | 10 | https://app.adam-tech.com/products/download/data_sheet/201605/ph1-xx-ua-data-sheet.pdf | J5 | N/A |  | Active | ROHS3 Compliant | EAR99 | 8536.69.4040 | Taiwan |  | 2057-PH1-07-UA-ND | https://media.digikey.com/Renders/Adam-Tech%20Renders/PH1-xx-UA.jpg
13 | 1050170001 | Molex | CONN RCPT USB2.0 MICRO B SMD R/A | 72,354 | In Stock |  | 1 | 1 | Cut Tape (CT) | WM1399CT-ND | 1.01000 | $1.01 | 1 |  | WM1399CT-ND | 13 | https://www.molex.com/pdm_docs/sd/1050170001_sd.pdf | J7 | May apply on shipments to the U.S. |  | Active | ROHS3 Compliant | EAR99 | 8536.69.4040 | China | https://www.molex.com/datasheets/rohspdf/1050170001_rohs.pdf | WM1399CT-ND | https://media.digikey.com/Photos/Molex/1050170001.jpg
14 | AC0603JR-101KL | YAGEO | RESISTOR SMD | 6,814 | In Stock |  | 2 | 2 | Cut Tape (CT) | 13-AC0603JR-101KLCT-ND | 0.10000 | $0.20 | 1 |  | 13-AC0603JR-101KLCT-ND | 20 | https://www.yageo.com/upload/media/product/productsearch/datasheet/rchip/PYu-AC_51_RoHS_L_9.pdf | R1, R5 | N/A |  | Active | ROHS3 Compliant | EAR99 | 8533.21.0030 | Taiwan |  | 13-AC0603JR-101KLCT-ND | https://media.digikey.com/Renders/Yageo%20Renders/AC-Series--SMD-Chip-Resistor.jpg
15 | RT0603DRE10100KL | YAGEO | RES 100K OHM 0.5% 1/10W 0603 | 31,081 | In Stock |  | 2 | 2 | Cut Tape (CT) | 13-RT0603DRE10100KLCT-ND | 0.11000 | $0.22 | 1 |  | 13-RT0603DRE10100KLCT-ND | 22 | https://www.yageo.com/upload/media/product/productsearch/datasheet/rchip/PYu-RT_1-to-0.01_RoHS_L_13.pdf | R2, R3 | N/A |  | Active | ROHS3 Compliant | EAR99 | 8533.21.0030 | Taiwan |  | 13-RT0603DRE10100KLCT-ND | https://media.digikey.com/Renders/Yageo%20Renders/RT-Series-Chip-Resistor.jpg
16 | RE0201BRE0710KL | YAGEO | RES SMD 10K OHM 0.1% 1/20W 0201 | 40,714 | In Stock |  | 1 | 1 | Cut Tape (CT) | 13-RE0201BRE0710KLCT-ND | 0.63000 | $0.63 | 1 |  | 13-RE0201BRE0710KLCT-ND | 20 | https://www.yageo.com/upload/media/product/productsearch/datasheet/rchip/PYu-RE_105_RoHS_L_6.pdf | R4 | N/A |  | Active | ROHS3 Compliant | EAR99 | 8533.21.0030 | Taiwan |  | 13-RE0201BRE0710KLCT-ND | https://media.digikey.com/Renders/Yageo%20Renders/1206-(3216-Metric).jpg
17 | RC0603JR-071ML | YAGEO | RES 1M OHM 5% 1/10W 0603 | 534,383 | In Stock |  | 1 | 1 | Cut Tape (CT) | 311-1.0MGRCT-ND | 0.10000 | $0.10 | 1 |  | 311-1.0MGRCT-ND | 20 | https://www.yageo.com/upload/media/product/productsearch/datasheet/rchip/PYu-RC_Group_51_RoHS_L_12.pdf | R6 | May apply on shipments to the U.S. |  | Active | ROHS3 Compliant | EAR99 | 8533.21.0030 | Taiwan | https://www.yageo.com/en/Download/Index/certificates#rchip | 311-1.0MGRCT-ND | https://media.digikey.com/Renders/Yageo%20Renders/0603-(1608-Metric).jpg
18 | RC0603JR-0712KL | YAGEO | RES 12K OHM 5% 1/10W 0603 | 464,245 | In Stock |  | 1 | 1 | Cut Tape (CT) | 311-12KGRCT-ND | 0.10000 | $0.10 | 1 |  | 311-12KGRCT-ND | 20 | https://www.yageo.com/upload/media/product/productsearch/datasheet/rchip/PYu-RC_Group_51_RoHS_L_12.pdf | R7 | May apply on shipments to the U.S. |  | Active | ROHS3 Compliant | EAR99 | 8533.21.0030 | Taiwan | https://www.yageo.com/en/Download/Index/certificates#rchip | 311-12KGRCT-ND | https://media.digikey.com/Renders/Yageo%20Renders/0603-(1608-Metric).jpg
19 | RC0603JR-1347KL | YAGEO | RES 47K OHM 5% 1/10W 0603 | 51,685 | In Stock |  | 1 | 1 | Cut Tape (CT) | 13-RC0603JR-1347KLCT-ND | 0.10000 | $0.10 | 1 |  | 13-RC0603JR-1347KLCT-ND | 20 | https://www.yageo.com/upload/media/product/productsearch/datasheet/rchip/PYu-RC_Group_51_RoHS_L_12.pdf | R8 | N/A |  | Active | ROHS3 Compliant | EAR99 | 8533.21.0030 | Taiwan | https://www.yageo.com/en/Download/Index/certificates#rchip | 13-RC0603JR-1347KLCT-ND | https://media.digikey.com/Renders/Yageo%20Renders/0603-(1608-Metric).jpg
20 | PCM13SMTR | C&K | SWITCH SLIDE SP3T 300MA 6V | 2,463 | In Stock |  | 2 | 2 | Cut Tape (CT) | 401-2017-1-ND | 0.98000 | $1.96 | 1 |  | 401-2017-1-ND | 9 | https://www.ckswitches.com/media/1424/pcm.pdf | SW1, SW3 | May apply on shipments to the U.S. |  | Active | ROHS3 Compliant | EAR99 | 8536.50.9050 | China | https://www.ckswitches.com/media/3448/rohs-reach-compliance-certificate.pdf | 401-2017-1-ND | https://media.digikey.com/Photos/CK%20Comp%20Photos/PCM13SMTR.JPG
21 | A6S-3102-H | Omron Electronics Inc-EMC Div | SWITCH SLIDE DIP SPST 25MA 24V | 16,075 | In Stock |  | 1 | 1 | Tube | SW1230-ND | 2.41000 | $2.41 | 1 |  | SW1230-ND | 30 | https://omronfs.omron.com/en_US/ecb/products/pdf/en-a6s.pdf | SW2 | May apply on shipments to the U.S. |  | Active | RoHS Compliant | EAR99 | 8536.50.9065 | China |  | SW1230-ND | https://media.digikey.com/Photos/Omron%20Elect%20Photos/A6S-3101-H.JPG
22 | 441-PRS21001-12 | Aries Electronics | CONN SOCKET PGA ZIF GOLD | 124 | In Stock |  | 1 | 1 | Bulk | A318-ND | 164.97000 | $164.97 | 1 |  | A318-ND | 6 | https://www.arieselec.com/wp-content/uploads/2020/12/10004-pga-zif-test-and-burn-in-socket.pdf | U1 | N/A |  | Active | ROHS3 Compliant | EAR99 | 8536.69.4040 | United States | https://www.arieselec.com/wp-content/uploads/2020/05/RoHS-3-Declaration.pdf|https://www.arieselec.com/wp-content/uploads/2021/03/REACH-211-Compliance-Statement.pdf | A318-ND | https://media.digikey.com/photos/Aries/441-PRS21001-12.jpg
23 | TLV71209DBVR | Texas Instruments | IC REG LINEAR 0.9V 300MA SOT23-5 | 3,000 | In Stock |  | 1 | 1 | Cut Tape (CT) | 296-46455-1-ND | 0.62000 | $0.62 | 1 |  | 296-46455-1-ND | 6 | https://www.ti.com/general/docs/suppproductinfo.tsp?distId=10 | U2 | N/A |  | Active | ROHS3 Compliant | EAR99 | 8542.39.0001 | Thailand |  | 296-46455-1-ND | https://media.digikey.com/Renders/Texas%20Instr%20Renders/296~4073253-4~DBV~5.JPG
24 | TLV71211DBVR | Texas Instruments | IC REG LINEAR 1.1V 300MA SOT23-5 | 3,533 | In Stock |  | 1 | 1 | Cut Tape (CT) | 296-30593-1-ND | 0.62000 | $0.62 | 1 |  | 296-30593-1-ND | 6 | https://www.ti.com/general/docs/suppproductinfo.tsp?distId=10 | U3 | N/A |  | Active | ROHS3 Compliant | EAR99 | 8542.39.0001 | Thailand |  | 296-30593-1-ND | https://media.digikey.com/Renders/Texas%20Instr%20Renders/296~4073253-4~DBV~5.JPG
25 | FT4222HQ-D-R | FTDI, Future Technology Devices International Ltd | IC BRIDGE USB TO I2C/SPI 32VQFN | 18,108 | In Stock |  | 1 | 1 | Cut Tape (CT) | 768-1362-1-ND | 3.63000 | $3.63 | 1 |  | 768-1362-1-ND | 18 | https://www.ftdichip.com/Support/Documents/DataSheets/ICs/DS_FT4222H.pdf | U4 | N/A |  | Active | ROHS3 Compliant | EAR99 | 8542.39.0001 | Taiwan | https://ftdichip.com/wp-content/uploads/2021/09/REACH-Statement-IC-Products-FTDI-QD_100.pdf|https://ftdichip.com/wp-content/uploads/2020/08/Rohs-Statement-Devices-QD_104.pdf | 768-1362-1-ND | https://media.digikey.com/Renders/Freescale%20Renders/32-VFQFN%20Exposed%20Pad.jpg
26 | ECS-120-18-23A-EN-TR | ECS Inc. | CRYSTAL 12.0000MHZ 18PF SMD | 28,476 | In Stock |  | 1 | 1 | Cut Tape (CT) | XC1659CT-ND | 1.14000 | $1.14 | 1 |  | XC1659CT-ND | 17 | https://ecsxtal.com/store/pdf/ecx-64a_ecx-64cr.pdf | Y1 | N/A |  | Active | ROHS3 Compliant | EAR99 | 8541.60.0050 | South Korea |  | XC1659CT-ND | https://media.digikey.com/Photos/ECS%20Photos/ECX-64A%20SERIES.JPG

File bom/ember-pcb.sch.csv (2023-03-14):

Source: | /Users/akashlevy/Documents/ember-pcb/ember-pcb.kicad_sch
Date: | Tuesday, March 14, 2023 at 11:31:51 AM
Tool: | Eeschema (6.0.9-0)
Generator: | /Applications/KiCad/KiCad.app/Contents/SharedSupport/plugins/bom_csv_grouped_by_value_with_fp.py
Component Count: | 53
Ref | Qnty | Value | Cmp name | Footprint | Description | Vendor
C1, C3, C6, C8, | 4 | 22uF | C_Polarized | Capacitor_Tantalum_SMD:CP_EIA-3528-21_Kemet-B | Polarized capacitor
C2, C5, C7, C10, C14, | 5 | 100nF | C | Capacitor_SMD:C_1210_3225Metric | Unpolarized capacitor
C4, C9, | 2 | 10uF | C_Polarized | Capacitor_Tantalum_SMD:CP_EIA-3528-12_Kemet-T | Polarized capacitor
C11, C12, | 2 | 27pF | C | Capacitor_SMD:C_0603_1608Metric | Unpolarized capacitor
C13, | 1 | 4.7u | C_Polarized | Capacitor_Tantalum_SMD:CP_EIA-3528-12_Kemet-T | Polarized capacitor
D1, D2, | 2 | LED | LED | LED_SMD:LED_0603_1608Metric | Light emitting diode
FB1, FB2, | 2 | FerriteBead | FerriteBead | Ferrite_THT:LairdTech_28C0236-0JW-10 | Ferrite bead
FID1, FID2, FID3, | 3 | Fiducial | Fiducial | Fiducial:Fiducial_1mm_Mask3mm | Fiducial Marker
H1, H2, | 2 | MountingHole | MountingHole_Pad | MountingHole:MountingHole_2.5mm_Pad | Mounting Hole with connection
H3, H4, | 2 | MountingHole | MountingHole | MountingHole:MountingHole_2.5mm | Mounting Hole without connection
H5, H6, | 2 | MountingHole | MountingHole_Pad | MountingHole:MountingHole_3mm_Pad | Mounting Hole with connection
J1, | 1 | Samtec_ASP-134602-01 | Samtec_ASP-134602-01 | Connector_Samtec:Samtec_FMC_ASP-134602-01_10x40_P1.27mm_Vertical | Connector array, 10x40, 1.27mm pitch, male pins, gold finish, VITA 57.1 FMC, SMD
J2, | 1 | Conn_02x06_Odd_Even | Conn_02x06_Odd_Even | Connector_PinHeader_2.54mm:PinHeader_2x06_P2.54mm_Vertical | Generic connector, double row, 02x06, odd/even pin numbering scheme (row 1 odd numbers, row 2 even numbers), script generated (kicad-library-utils/schlib/autogen/connector/)
J3, J6, J8, J9, | 4 | Conn_Coaxial_Power | Conn_Coaxial_Power | Connector_Coaxial:SMA_Molex_73251-2200_Horizontal | coaxial connector (BNC, SMA, SMB, SMC, Cinch/RCA, LEMO, ...)
J4, | 1 | Conn_02x12_Odd_Even | Conn_02x12_Odd_Even | Connector_PinHeader_2.54mm:PinHeader_2x12_P2.54mm_Vertical | Generic connector, double row, 02x12, odd/even pin numbering scheme (row 1 odd numbers, row 2 even numbers), script generated (kicad-library-utils/schlib/autogen/connector/)
J5, | 1 | Conn_01x07 | Conn_01x07 | Connector_PinHeader_2.54mm:PinHeader_1x07_P2.54mm_Vertical | Generic connector, single row, 01x07, script generated (kicad-library-utils/schlib/autogen/connector/)
J7, | 1 | USB_B_Micro | USB_B_Micro | Connector_USB:USB_Micro-B_Molex-105017-0001 | USB Micro Type B connector
R1, R5, | 2 | 1k | R | Resistor_SMD:R_0603_1608Metric | Resistor
R2, R3, | 2 | 100k | R | Resistor_SMD:R_0603_1608Metric | Resistor
R4, | 1 | 10k | R | Resistor_SMD:R_0603_1608Metric | Resistor
R6, | 1 | 1M | R | Resistor_SMD:R_0603_1608Metric | Resistor
R7, | 1 | 12k | R | Resistor_SMD:R_0603_1608Metric | Resistor
R8, | 1 | 47k | R | Resistor_SMD:R_0603_1608Metric | Resistor
SW1, SW3, | 2 | SW_SP3T | SW_SP3T | Button_Switch_SMD:SW_SP3T_PCM13 | Switch, three position, single pole triple throw, 3 position switch, SP3T
SW2, | 1 | SW_DIP_x03 | SW_DIP_x03 | Button_Switch_SMD:SW_DIP_SPSTx03_Slide_Omron_A6S-310x_W8.9mm_P2.54mm | 3x DIP Switch, Single Pole Single Throw (SPST) switch, small symbol
TP1, | 1 | TestPointHeartbeat | TestPoint | TestPoint:TestPoint_Pad_D1.0mm | test point
U1, | 1 | EMBER Macro | EMBER_Macro | ZIF:ARIES_441-PRS21001-12
U2, | 1 | TLV71209_SOT23-5 | TLV71209_SOT23-5 | Package_TO_SOT_SMD:SOT-23-5 | 300mA Low Dropout Voltage Regulator, Fixed Output 0.9V, SOT-23-5
U3, | 1 | TLV71211_SOT23-5 | TLV71211_SOT23-5 | Package_TO_SOT_SMD:SOT-23-5 | 300mA Low Dropout Voltage Regulator, Fixed Output 1.1V, SOT-23-5
U4, | 1 | FT4222HQ | FT4222HQ | Package_DFN_QFN:VQFN-32-1EP_5x5mm_P0.5mm_EP3.1x3.1mm | USB 2.0 to Quad SPI or I2C Bridge, VQFN-32
Y1, | 1 | 12MHz | Crystal | Crystal:Crystal_SMD_0603-2Pin_6.0x3.5mm | Two pin crystal

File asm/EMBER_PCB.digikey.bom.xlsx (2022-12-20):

Country of Origin may be different at time of shipment.
The HTSUS and ECCN information shown is for informational purposes only and is not a representation or warranty as to the accuracy or reliability of these classifications. All information is provided "as is" and is subject to change without notice. Any use made of the information provided is without recourse to Digi-Key and at the user's risk.
Index | Manufacturer Part Number | Manufacturer Name | Description | Availability | Stock Status | Attrition % | Requested Quantity 1 | Pack Quantity 1 | Pack Type 1 | Digi-Key Part Number 1 | Unit Price 1 | Extended Price 1 | Minimum Order Quantity 1 | Customer Reference | Requested Part Number | Lead Weeks | Datasheet | Reference Designator | US Import Tariff | Note | Part Status | RoHS Status | ECCN | HTSUS | Country of Origin | Environmental Information | Original Part numbers | Image
1 | 28C0236-0JW-10 | Laird-Signal Integrity Products | FERRITE BEAD 998 OHM RADIAL 1LN | 133,536 | In Stock |  | 2 | 2 | Bulk | 240-2493-ND | 0.90000 | $1.80 | 1 |  | 240-2493-ND | 22 | https://media.digikey.com/pdf/Data%20Sheets/Laird%20Technologies/EMI_Filtering_and_RF_Inductors.pdf | FB1, FB2 | N/A |  | Active | ROHS3 Compliant | EAR99 | 8548.00.0000 | China |  | 240-2493-ND | https://media.digikey.com/photos/Steward%20Photos/28C0236-0JW-10.jpg
2 | 441-PRS21001-12 | Aries Electronics | CONN SOCKET PGA ZIF GOLD | 0 | Normally Stocking |  | 1 | 1 | Bulk | A318-ND | 164.97000 | $164.97 | 1 |  | A318-ND | 6 | https://www.arieselec.com/wp-content/uploads/2020/12/10004-pga-zif-test-and-burn-in-socket.pdf | U1 | N/A |  | Active | ROHS3 Compliant | EAR99 | 8536.69.4040 | United States | https://www.arieselec.com/wp-content/uploads/2020/05/RoHS-3-Declaration.pdf|https://www.arieselec.com/wp-content/uploads/2021/03/REACH-211-Compliance-Statement.pdf | A318-ND | https://media.digikey.com/photos/Aries/441-PRS21001-12.jpg
3 | LP5912-0.9DRVT | Texas Instruments | IC REG LINEAR 0.9V 500MA 6WSON | 708 | In Stock |  | 1 | 1 | Cut Tape (CT) | 296-44154-1-ND | 1.60000 | $1.60 | 1 |  | 296-44154-1-ND | 6 | http://www.ti.com/general/docs/suppproductinfo.tsp?distId=10 | U2 | N/A |  | Active | ROHS3 Compliant | EAR99 | 8542.39.0001 | Philippines |  | 296-44154-1-ND | https://media.digikey.com/Renders/Texas%20Instr%20Renders/296~4222173~DRV~6.jpg
4 | LP5912-1.1DRVT | Texas Instruments | IC REG LINEAR 1.1V 500MA 6WSON | 694 | In Stock |  | 1 | 1 | Cut Tape (CT) | 296-46644-1-ND | 1.60000 | $1.60 | 1 |  | 296-46644-1-ND | 12 | http://www.ti.com/general/docs/suppproductinfo.tsp?distId=10 | U3 | N/A |  | Active | ROHS3 Compliant | EAR99 | 8542.39.0001 | Philippines |  | 296-46644-1-ND | https://media.digikey.com/Renders/Texas%20Instr%20Renders/296~4222173~DRV~6.jpg
5 | LP5912-2.5DRVT | Texas Instruments | IC REG LINEAR 2.5V 500MA 6WSON | 266 | In Stock |  | 1 | 1 | Cut Tape (CT) | 296-52223-1-ND | 1.60000 | $1.60 | 1 |  | 296-52223-1-ND | 6 | http://www.ti.com/general/docs/suppproductinfo.tsp?distId=10 | U4 | May apply on shipments to the U.S. |  | Active | ROHS3 Compliant | EAR99 | 8542.39.0001 | China |  | 296-52223-1-ND | https://media.digikey.com/Renders/Texas%20Instr%20Renders/296~4222173~DRV~6.jpg
6 | LT Q39E-Q1OO-25-1 | OSRAM Opto (ams OSRAM) | LED GREEN DIFFUSED 0603 SMD | 17,350 | In Stock |  | 1 | 1 | Cut Tape (CT) | 475-3441-1-ND | 0.43000 | $0.43 | 1 |  | 475-3441-1-ND | 14 | https://dammedia.osram.info/media/resource/hires/osram-dam-2493475/LT%20Q39E.pdf | D1 | N/A |  | Active | ROHS3 Compliant | EAR99 | 8541.41.0000 | Taiwan |  | 475-3441-1-ND | https://media.digikey.com/Renders/Osram%20Opto%20Renders/LB-Q39E.jpg
7 | ASP-134602-01 | Samtec Inc. | CONN ARRAY PLUG 400POS SMD GOLD | 2,131 | In Stock |  | 1 | 1 | Cut Tape (CT) | 612-ASP-134602-01CT-ND | 29.88000 | $29.88 | 1 |  | 612-ASP-134602-01CT-ND | 11 | http://suddendocs.samtec.com/prints/asp-134602-01.pdf | J1 | N/A |  | Active | ROHS3 Compliant | EAR99 | 8536.69.4040 | Costa Rica |  | 612-ASP-134602-01CT-ND | https://media.digikey.com/Photos/Samtec%20Photos/ASP-134602-01_TOP.JPG
8 | 0732512200 | Molex | CONN SMA JACK R/A 50 OHM PCB | 26,937 | In Stock |  | 2 | 2 | Bulk | WM9352-ND | 6.88000 | $13.76 | 1 |  | WM9352-ND | 8 | https://www.molex.com/pdm_docs/sd/732512200_sd.pdf | J2, J5 | N/A |  | Active | ROHS3 Compliant | EAR99 | 8536.69.4010 | Taiwan | https://www.molex.com/datasheets/rohspdf/0732512200_rohs.pdf | WM9352-ND | https://media.digikey.com/Photos/Molex/0732512200.jpg
9 | PH2-12-UA | Adam Tech | CONN HEADER VERT 12POS 2.54MM | 19,939 | In Stock |  | 1 | 1 | Bag | 2057-PH2-12-UA-ND | 0.20000 | $0.20 | 1 |  | 2057-PH2-12-UA-ND | 10 | https://app.adam-tech.com/products/download/data_sheet/202065/ph2-xx-ua-data-sheet.pdf | J3 | N/A |  | Active | ROHS3 Compliant | EAR99 | 8536.69.4040 | Taiwan |  | 2057-PH2-12-UA-ND | https://media.digikey.com/Renders/Adam-Tech%20Renders/PH2-xx-UA.jpg
10 | PH1-07-UA | Adam Tech | CONN HEADER VERT 7POS 2.54MM | 23,741 | In Stock |  | 1 | 1 | Bag | 2057-PH1-07-UA-ND | 0.15000 | $0.15 | 1 |  | 2057-PH1-07-UA-ND | 10 | https://app.adam-tech.com/products/download/data_sheet/201605/ph1-xx-ua-data-sheet.pdf | J4 | N/A |  | Active | ROHS3 Compliant | EAR99 | 8536.69.4040 | Taiwan |  | 2057-PH1-07-UA-ND | https://media.digikey.com/Renders/Adam-Tech%20Renders/PH1-xx-UA.jpg
11 | AC0603JR-101KL | YAGEO | RESISTOR SMD | 58,836 | In Stock |  | 1 | 1 | Cut Tape (CT) | 13-AC0603JR-101KLCT-ND | 0.10000 | $0.10 | 1 |  | 13-AC0603JR-101KLCT-ND | 20 | https://www.yageo.com/upload/media/product/productsearch/datasheet/rchip/PYu-AC_51_RoHS_L_9.pdf | R1 | N/A |  | Active | ROHS3 Compliant | EAR99 | 8533.21.0030 | Taiwan |  | 13-AC0603JR-101KLCT-ND | https://media.digikey.com/Renders/Yageo%20Renders/AC-Series--SMD-Chip-Resistor.jpg
12 | RT0603DRE10100KL | YAGEO | CHIP RESISTOR THIN FLIM HIGH PRE | 9,069 | In Stock |  | 2 | 2 | Cut Tape (CT) | 13-RT0603DRE10100KLCT-ND | 0.11000 | $0.22 | 1 |  | 13-RT0603DRE10100KLCT-ND | 22 | https://www.yageo.com/upload/media/product/productsearch/datasheet/rchip/PYu-RT_1-to-0.01_RoHS_L_13.pdf | R2, R3 | N/A |  | Active | ROHS3 Compliant | EAR99 | 8533.21.0030 | Taiwan |  | 13-RT0603DRE10100KLCT-ND | https://media.digikey.com/Renders/Yageo%20Renders/RT-Series-Chip-Resistor.jpg
13 | PCM13SMTR | C&K | SWITCH SLIDE SP3T 300MA 6V | 8,339 | In Stock |  | 2 | 2 | Cut Tape (CT) | 401-2017-1-ND | 1.02000 | $2.04 | 1 |  | 401-2017-1-ND | 9 | https://www.ckswitches.com/media/1424/pcm.pdf | SW1, SW2 | May apply on shipments to the U.S. |  | Active | ROHS3 Compliant | EAR99 | 8536.50.9050 | China | https://www.ckswitches.com/media/3448/rohs-reach-compliance-certificate.pdf | 401-2017-1-ND | https://media.digikey.com/Photos/CK%20Comp%20Photos/PCM13SMTR.JPG
14 | A6S-2101-H | Omron Electronics Inc-EMC Div | SWITCH SLIDE DIP SPST 25MA 24V | 657 | In Stock |  | 1 | 1 | Bulk | Z5188-ND | 2.12000 | $2.12 | 1 |  | Z5188-ND | 27 | https://omronfs.omron.com/en_US/ecb/products/pdf/en-a6s.pdf | SW3 | May apply on shipments to the U.S. |  | Active | RoHS Compliant | EAR99 | 8536.50.9065 | China |  | Z5188-ND | https://media.digikey.com/Photos/Omron%20Elect%20Photos/A6S-2101-H.jpg
15 | T495B226K010ATE500 | KEMET | CAP TANT 22UF 10% 10V 1411 | 3,457 | In Stock |  | 4 | 4 | Cut Tape (CT) | 399-18339-1-ND | 1.57000 | $6.28 | 1 |  | 399-18339-1-ND | 44 | https://api.kemet.com/component-edge/download/datasheet/T495B226K010ATE500.pdf | C1, C3, C6, C8 | N/A |  | Active | ROHS3 Compliant | EAR99 | 8532.21.0050 | Mexico |  | 399-18339-1-ND | https://media.digikey.com/Photos/Kemet%20Photos/MFG_T495-Series.jpg
16 | C3225X7T2J104K160AE | TDK Corporation | CAP CER 0.1UF 630V X7T 1210 | 19,884 | In Stock |  | 4 | 4 | Cut Tape (CT) | 445-8907-1-ND | 0.65000 | $2.60 | 1 |  | 445-8907-1-ND | 28 | https://product.tdk.com/system/files/dam/doc/product/capacitor/ceramic/mlcc/catalog/mlcc_commercial_soft_en.pdf | C2, C5, C7, C10 | N/A |  | Active | ROHS3 Compliant | EAR99 | 8532.24.0020 | Japan | https://product.tdk.com/system/files/dam/doc/product/capacitor/ceramic/mlcc/rohs/mlccrohs_commercial_soft_en.pdf|https://product.tdk.com/en/environment/index.html | 445-8907-1-ND | https://media.digikey.com/Renders/TDK%20Renders/1210-(3225-Metric)-2,80mm-C-Series.jpg
17 | T494B106K025AT | KEMET | CAP TANT 10UF 10% 25V 1411 | 15,393 | In Stock |  | 2 | 2 | Cut Tape (CT) | 399-5126-1-ND | 1.48000 | $2.96 | 1 |  | 399-5126-1-ND | 56 | https://api.kemet.com/component-edge/download/datasheet/T494B106K025AT.pdf | C4, C9 | N/A |  | Active | ROHS3 Compliant | EAR99 | 8532.21.0050 | Mexico |  | 399-5126-1-ND | https://media.digikey.com/photos/Kemet%20Photos/T494B685K016AT.JPG

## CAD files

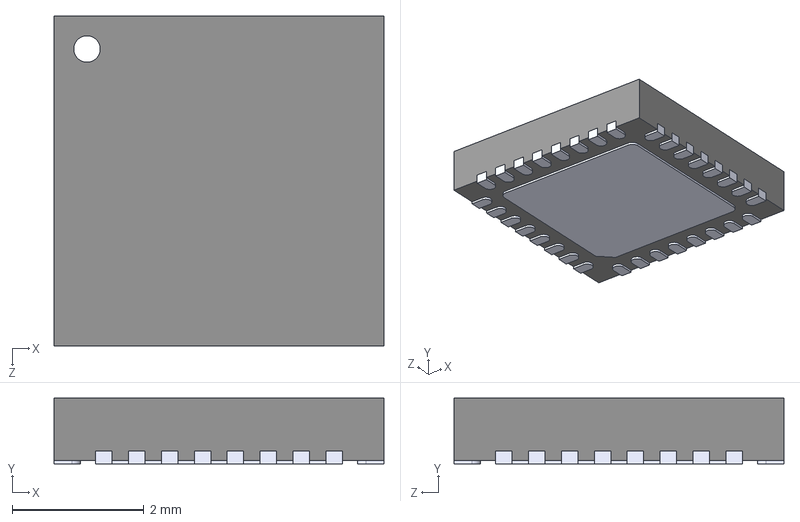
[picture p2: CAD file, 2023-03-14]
components/QFN32.STEP
5.00 x 1.00 x 5.00 mm

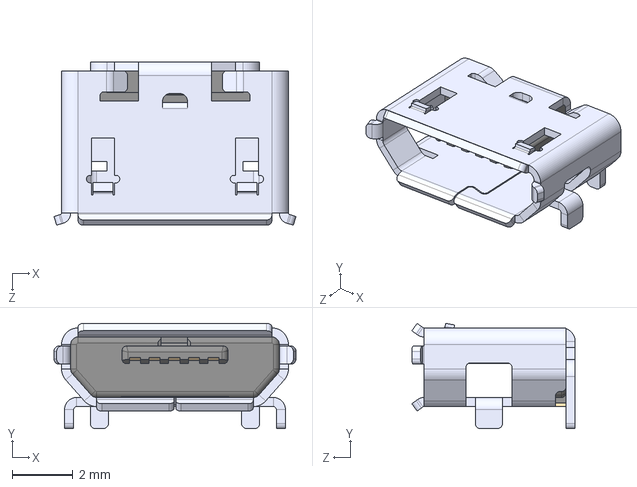
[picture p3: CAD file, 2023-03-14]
components/1050170001--3DModel-STEP-1.STEP
8.00 x 3.48 x 5.40 mm

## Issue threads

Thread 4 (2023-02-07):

V2 fixes

akashlevy, 2023-02-07:
Several improvements could be implemented for V2:

1. Remove 2.5V regulator, use SPDT switch to supply from coaxial or VADJ (configured to 2.5V or 3.3V)
2. [Implement PMOD Interface Type 2A, expanded SPI](https://digilent.com/reference/pmod/start)
3. Add coaxial headers routed to user clocks {CLK[0..1]_M2C_P} on FMC for dynamic clock
4. Implement FMC LPC for the 56 critical signals: SPI, {mclk_pause, rram_busy, rst_n}, {sa_do[47:0], sa_rdy}
5. Implement FMC HPC for the rest of the signals (161 in total): put sa_clk on CLK2_BIDIR_P and make sure to set CLKDIR for C2M
6. Label FMC header rows/columns in paste on both sides
7. Label socket/package pin rows/columns on both sides
8. FMC screw holes for easy connections
9. Larger mounting holes
10. SPST switch to short wl_source_pin to vddio
11. Pins for all FMC HPC signal pins: route unused pins to auxiliary header for use
12. Implement all power good LEDs
13. MAYBE: Ensure 5 mil trace and space everywhere with no same-net violations
14. MAYBE: Use on-chip regulators with larger pads to ease soldering

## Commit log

2022-12-19 Complete six-layer board
    [ember-pcb-B_Cu.gbr, ember-pcb-B_Mask.gbr, ember-pcb-B_Paste.gbr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]
2022-12-19 Fix schematic and update schematic checklist
    [ember-pcb.kicad_sch]
2022-12-19 Assembly files
2022-12-20 Add final stuff
    [EMBER_PCB.digikey.bom.xlsx, EMBER_PCB.jlcpcb.bom.xlsx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]
2023-03-14 PCB checklists/TODO updates
